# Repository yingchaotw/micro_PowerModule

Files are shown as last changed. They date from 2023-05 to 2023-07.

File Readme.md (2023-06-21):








# µPower Module

1. Purpose：

 - DC/DC Programmable small-wattage power supply
 - This project is [Open Source Hardware](https://www.oshwa.org/definition/chinese/)

2. Scope：
 - RFQ
     1. [x] Over voltage protection circuit
     2. [x] Support [MikroBus](https://www.mikroe.com/mikrobus) Foot Position
     3. [x] Positive and negative load voltage signals can be controlled by the H-bridge
     4. [x] Display voltage/current/wattage [Nokia 5110 LCD](https://github.com/EleonoreMizo/pedalevite/blob/master/doc/datasheets/Philips%20PCD8544%20-%20IC%2C%2048x84%20pixels%20matrix%20LCD%20controller%20(Nokia%205110).pdf), [TI-Nokia 5110 LCD](https://www.ti.com/lit/ml/swrp182/swrp182.pdf), [Nokia5110 LCD ](https://components101.com/displays/nokia-5110-lcd)
     5. [ ] MCU auto-regulator function
     6. [ ] Real time display of voltage and current
     7. [ ] Use a led to display local or remote mode
        1. [x] Standard Commands for Programmable Instruments

# HW Block Diagram


<BR/>
plug-in module. ex. Temperature sensor, etc.. <br/>

[Schematic Readme](./Circuit_microPowerModule/Readme.md)

# SW FlowChart
```mermaid
flowchart TD
subgraph "System Initialization"
  a("Check Communication<BR>(UART/I2C/SPI/..)") --> b(Check ADC) --> c(Read Sensor) --> d[buzzer <br> Make a sound]
end

subgraph "main"
    A(Start) --> B[System<br>Initialization]
    B --> C[Select Mode]
    C -->D["Remote <PC>"]
    C -->E["Local <encoder>"]
end

```

# Candidate Components

The required hardware units are divided into the following 6 items.
1. Power
2. Microcontroller
3. Interface
4. Sensor (Current/temperature)
5. Connector
6. Debug port

# PIN Assessment

[Raspberry Pi RP2040 GPIO Function](https://datasheets.raspberrypi.com/rp2040/rp2040-datasheet.pdf#_gpio_functions)

```
GPIO00 UART0 (Tx) --> RS485 (In)
GPIO01 UART0 (Rx) <-- RS485 (Out)
GPIO02 I2C1 (SDA) <-> (*Option) MikroBus SDA
GPIO03 I2C1 (SCL) --> (*Option) MikroBus SCL
GPIO04 I2C0 (SDA) <-> Power Management
GPIO05 I2C0 (SCL) --> Power Management
GPIO06 DS (MOSI)  --> Display Serial Input
GPIO07 DS (CLK)   --> Display Clock Input
GPIO08 UART1 (Tx) --> (*Option) MikroBus Tx
GPIO09 UART1 (Rx) <-- (*Option) MikroBus Rx
GPIO10 SPI1 (SCK) --> (*Option) MikroBus SCK
GPIO11 SPI1 (Tx)  --> (*Option) MikroBus SDI
GPIO12 SPI1 (Rx)  <-- (*Option) MikroBus SDO
GPIO13 SPI1 (nCS) --> (*Option) MikroBus CSS
GPIO14 DS (CE)    --> Display Chip Enable
GPIO15 DS (DC)    --> Display Data Command
GPIO16 PWM0_A     --> Buzzer
GPIO17 MkBus_RST  --> (*Option) MikroBus Reset
GPIO18 PWM1_A     --> (*Option) MikroBus PWM
GPIO19 PIO1_IRQ1  --> (*Option) MikroBus INT
GPIO20 PWM2_A     --> Encoder A phase
GPIO21 PWM2_B     --> Encoder B phase
GPIO22 RS_485 W/R --> RS485 (W/R)
GPIO23 DS_RST     --> Display Reset
GPIO24 ENC_SW     <-- Encoder Push Switch
GPIO25 PWM4 B     --> WS2512 LED Control
GPIO26 Monitor    <-- Input Power Monitor
GPIO27 ADC1       <-- (*Option) MikroBus ADC
GPIO28 Output_CTRL<-- Buck / Boost Switch
GPIO29 *Polarity  --> H-Bridge Control Load (Forward/Reverse)
```

# Potocol

[About Spec](./Document/Specification/Spec_link.md)
[Standard Commands for Programmable Instruments](https://www.ivifoundation.org/docs/scpi-99.pdf)

# Licenses & Disclaimer

<a rel="license" href="https://www.gnu.org/licenses/quick-guide-gplv3.en.html">GNU GPLv3</a> <br/> This work is licensed under a <a rel="license" href="https://www.gnu.org/licenses/quick-guide-gplv3.en.html"> GNU General Public License v3</a>.

If you have other ideas or suggestions, please feel free to submit an issue.
Welcome fork this repositories to provide contributions, or [buy me a coffee](https://ko-fi.com/yingchao_tw). thanks :)

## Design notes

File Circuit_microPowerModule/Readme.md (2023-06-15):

# Schematic







# ERC Report

```
ERC report (Thu 15 Jun 2023 20:53:31 CST, Encoding UTF8)

***** Sheet /

***** Sheet /main_contorl/

***** Sheet /Input_power/

***** Sheet /OutputPower/

***** Sheet /peripheral/

** ERC messages: 0  Errors 0  Warnings 0
```
[ERC File](./ERC.rpt)

# Incldue Library
[MikroBus](https://github.com/tclarke/kicad-mikroBUS)

# License & Disclaimer

<a rel="license" href="https://www.gnu.org/licenses/quick-guide-gplv3.en.html">GNU GPLv3</a> <br/> This work is licensed under a <a rel="license" href="https://www.gnu.org/licenses/quick-guide-gplv3.en.html"> GNU General Public License v3</a>.

If you have other ideas or suggestions, please feel free to submit an issue.
Welcome fork this repositories to provide contributions, or [buy me a coffee](https://ko-fi.com/yingchao_tw). thanks :)

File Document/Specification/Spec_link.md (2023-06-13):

# MCU

## Respberry Pi 2040
1. [official website](https://www.raspberrypi.com/documentation/microcontrollers/rp2040.html)
2. [DataSheet](https://datasheets.raspberrypi.com/rp2040/rp2040-datasheet.pdf)
3. [Getting Started](https://datasheets.raspberrypi.com/pico/getting-started-with-pico.pdf)
4. [Example C Code](https://github.com/raspberrypi/pico-examples/tree/master)
5. [Example Rust Code](https://github.com/rp-rs/rp2040-project-template)
6. [Waveshare Products](https://www.waveshare.com/product/rp2040-zero.htm)

# Load Driver
1. [L298-ST Website](https://www.st.com/en/motor-drivers/l298.html)
2. [L298N](https://www.st.com/resource/en/datasheet/l298.pdf)

# Protocol

[Standard Commands for Programmable Instrumentation](https://magna-power.com/assets/docs/html_ts/index-scpi.html)

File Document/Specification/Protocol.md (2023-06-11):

[Refer to SCPI website](https://magna-power.com/assets/docs/html_ts/index-scpi.html)

# SCPI

SYSTem:PRESet

SYSTem:VERSion

SYSTem:ERRor?

## CONFIGURE

CONFigure:TTLport

CONFigure:BEEPer

CONFigure:REMote

CONFigure:OUTPut

CONFigure:FOLDback

CONFigure:FOLDT

CONFigure:APGmode

CONFigure:MEASure:SPeed

CONFigure:AVG:TIMES

CONFigure:AVG:METHod

CONFigure:MSTSLV:NUMSLV

CONFigure:MSTSLV

## SOURCE

SOURce:VOLTage

SOURce:VOLTage:LIMit:{HIGH/LOW}

SOURce:VOLTage:PROTect:{HIGH/LOW}

SOURce:VOLTage:SLEW

SOURce:CURRent

SOURce:CURRent:LIMit:{HIGH/LOW}

SOURce:CURRent:PROTect:{HIGH/LOW}

SOURce:CURRent:SLEW

SOURce:CURRent:SLEWINF

SOURce:CURRent:SLEWINF DISABLE

SOUR:POW:PROT:HIGH

SOUR:DCON:{RISE/FALL}

## FETCJ

FETCh:VOLTage?

FETCh:CURRent?

FETCh:POWer?

FETCh:STATus?

## MEASURE

MEASure:VOLTage?

MEASure:CURRent?

MEASure:POWer?

## PROGRAM

PROGram:SELected

PROGram:LINK

PROGram:COUNT

PROGram:RUN

PROGram:PULL

PROGram:SAVE

PROGram:SEQuence:SELected

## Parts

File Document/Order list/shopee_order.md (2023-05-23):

# Module purchase list

|Item| Module name | Purchase Site | Price |
|:--:|---|---|---|
|1| MAX6675 | [Shopee](https://shp.ee/dakv5j8)| $98 |
|2| INA219[^INA219] | [Shopee](https://shp.ee/smzmpzs)| $98 |
|3| Buzzer | [Shopee](https://shp.ee/jidekbz)| $12 |
|4| Nokia 5110 | [Shopee](https://shp.ee/6gvhakf)| $99 |
|5| MAX485[^RS485] | [Shopee](https://shp.ee/49gyx4t) | $14 |
|6| Encoder | [Shopee](https://shp.ee/mrihj6k) | $19 |
|7| MCP4725 | [Shopee](https://shp.ee/vgvm73h) |$120|
|8| Boost | [Shopee](https://shp.ee/cv4cusn) |$15|
|9| Buck | [Shopee](https://shp.ee/qvjz9ka) |$32|
|10| OPA | [Shopee](https://shp.ee/ieca9kp) | $39|

[^INA219]:

[^RS485]:

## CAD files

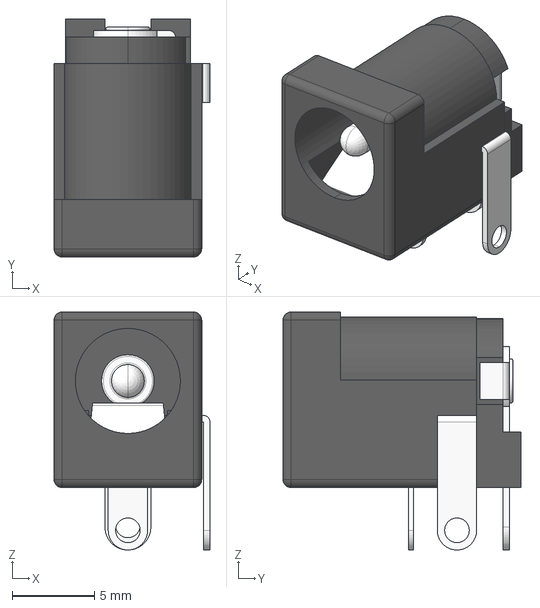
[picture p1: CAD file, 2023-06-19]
Circuit_microPowerModule/3D_Module/BarrelJack_Wuerth_6941xx301002.stp
9.50 x 14.5 x 14.5 mm

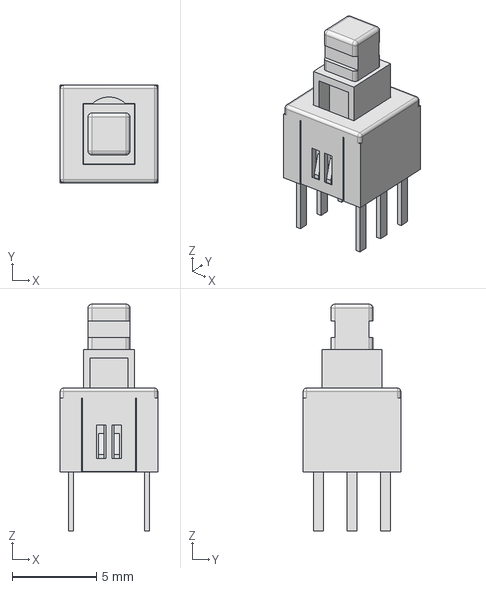
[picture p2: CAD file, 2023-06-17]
Circuit_microPowerModule/3D_Module/TL2203EE.stp
5.80 x 5.80 x 13.5 mm

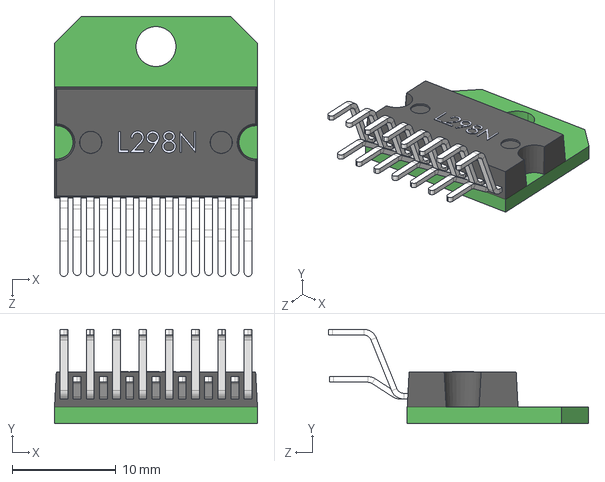
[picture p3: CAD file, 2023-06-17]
Circuit_microPowerModule/3D_Module/L298N.stp
19.6 x 9.09 x 25.1 mm

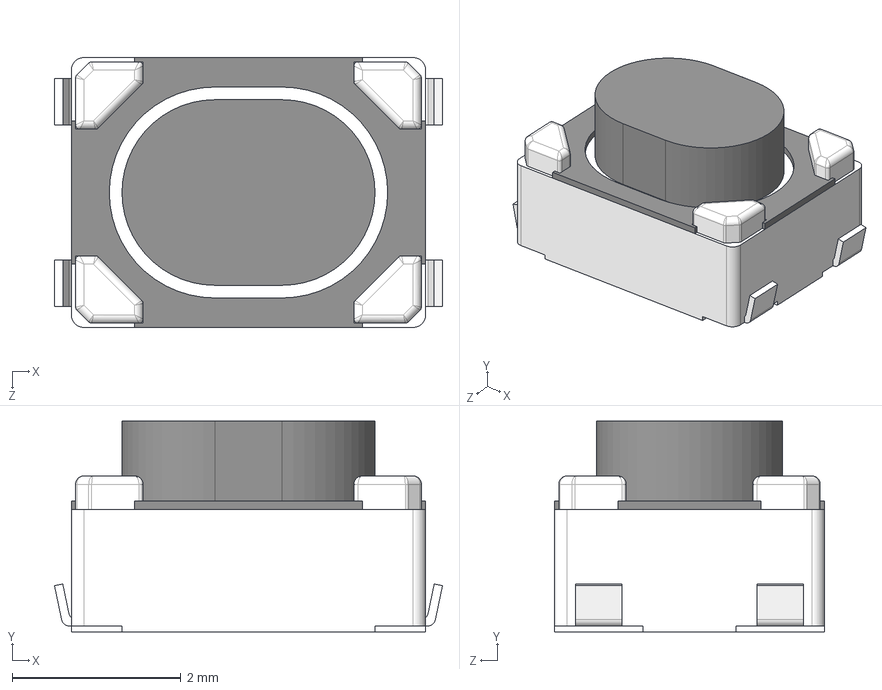
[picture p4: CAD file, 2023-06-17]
Circuit_microPowerModule/3D_Module/PTS815_SJK_250_SMTR_LFS.stp
4.60 x 2.50 x 3.20 mm

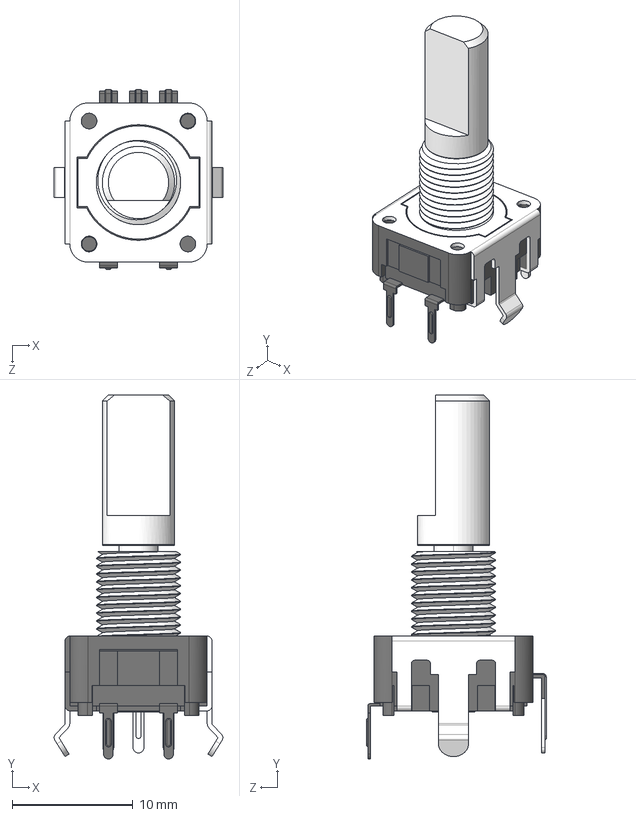
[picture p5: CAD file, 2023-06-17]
Circuit_microPowerModule/3D_Module/Encoder.stp
14.0 x 30.2 x 14.9 mm

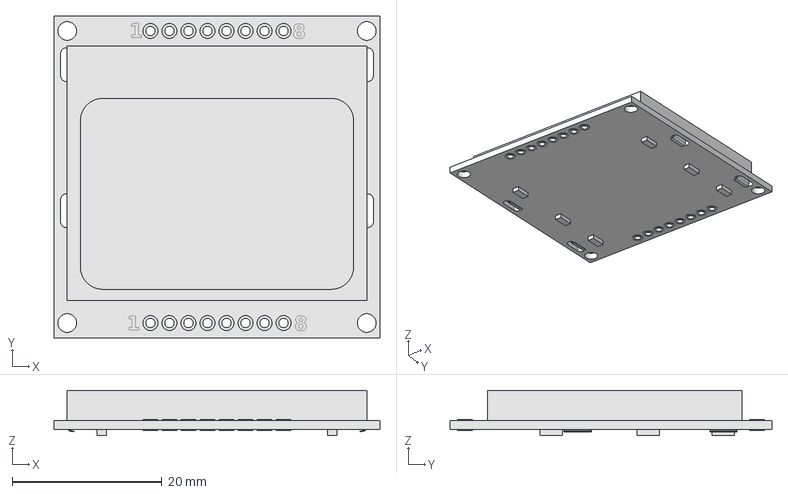
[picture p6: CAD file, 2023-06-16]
Circuit_microPowerModule/3D_Module/Nokia_5110_LCD.FCStd
43.5 x 43.0 x 6.05 mm

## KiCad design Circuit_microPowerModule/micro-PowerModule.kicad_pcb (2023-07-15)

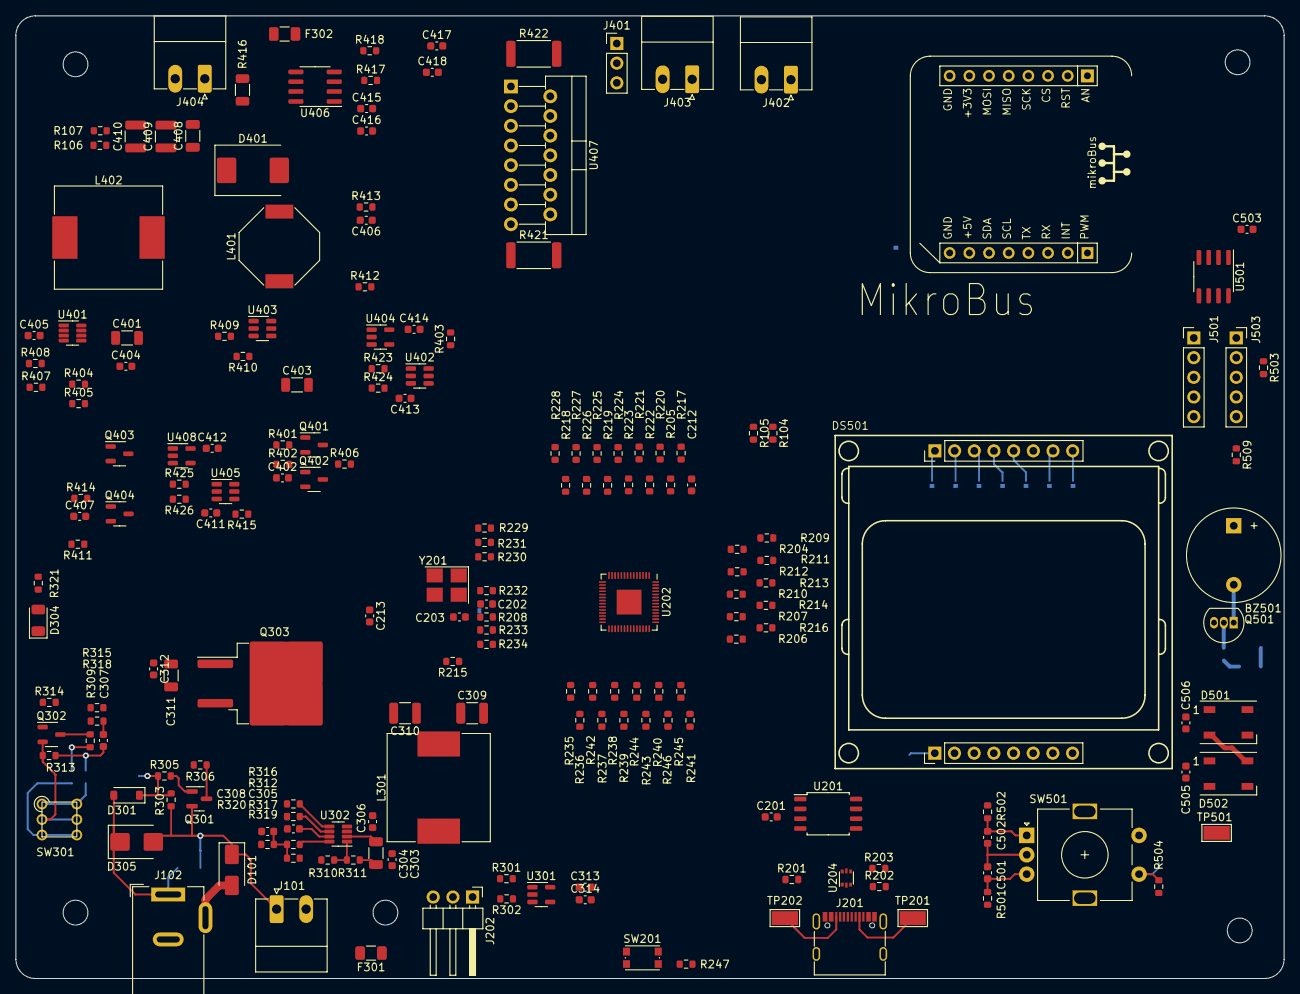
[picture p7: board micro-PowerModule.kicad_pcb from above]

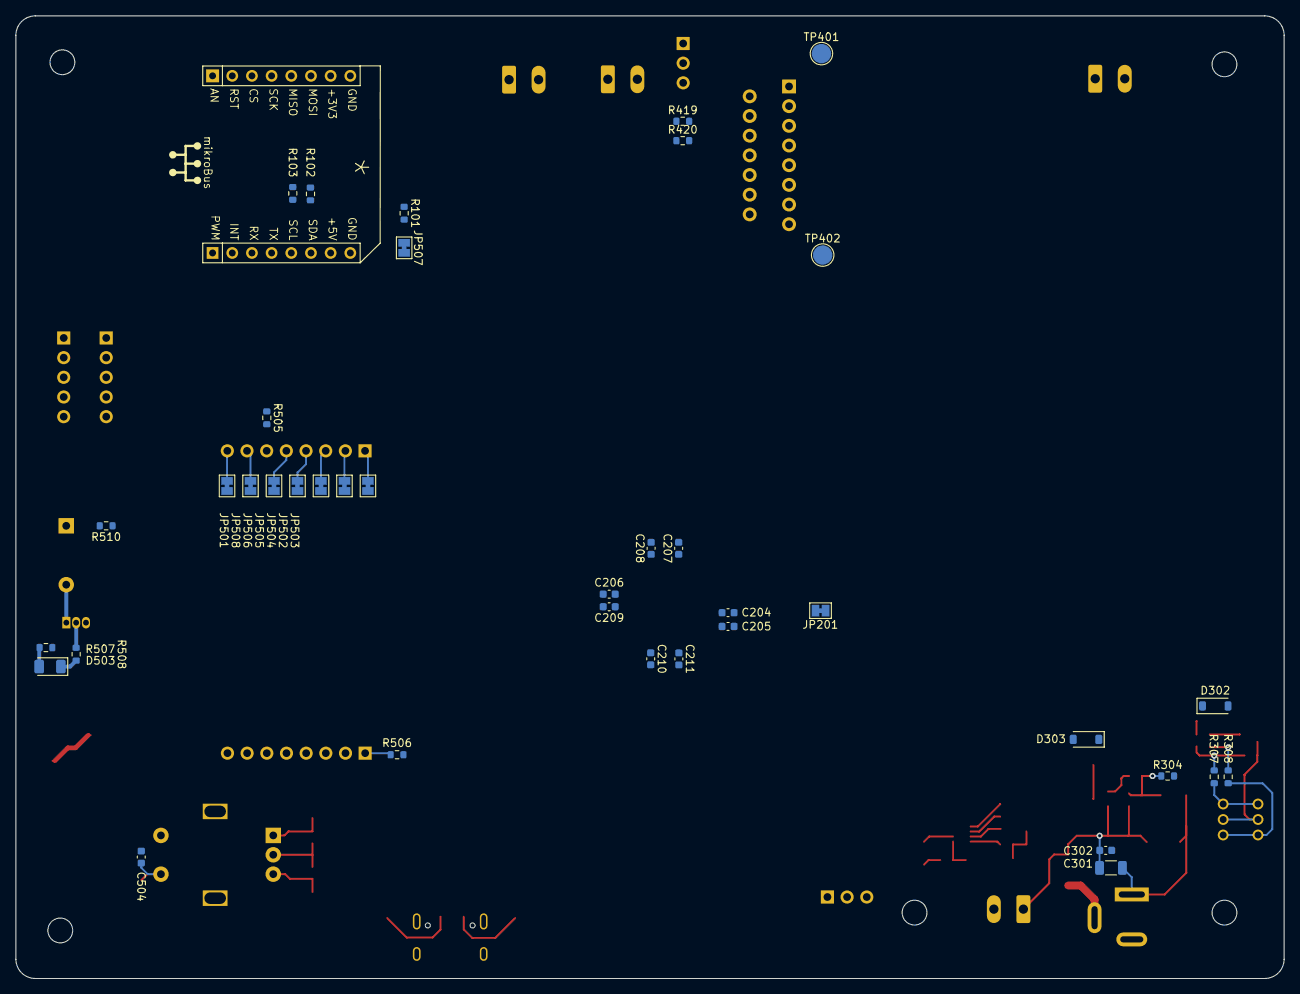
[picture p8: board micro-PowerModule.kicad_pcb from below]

Board: 2 copper layers, 163.7 x 124.2 mm, 235 parts (38 on the bottom side), 177 nets.

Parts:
BZ501: Buzzer; Buzzer_12x9.5RM7.6
C201, C204, C205, C206, C207, C208, C209, C210, C211, C212, C303, C305, C306, C313, C314, C404, C405, C411, C412, C413, C414, C415, C416, C417, C418, C501, C502, C503, C505, C506: 100nF/50V; C_0603_1608Metric
C202, C203: 15pF/50V; C_0603_1608Metric
C213, C402, C407: 10pF/50V; C_0603_1608Metric
C301, C311: 47u/50V; C_1206_3216Metric
C302, C312: 100n/50V; C_0603_1608Metric
C304, C401, C403, C408: 22uF/50V; C_1206_3216Metric
C307: 10n/50V; C_0603_1608Metric
C308, C406: 33pF/50V; C_0603_1608Metric
C309, C310, C409, C410: 22uF/50V; C_1210_3225Metric
C504: 10nF/50V; C_0603_1608Metric
D101: SS54; D_SMA
D301: Zener_24V/500mW; D_SOD-123
D302: DNP; D_SOD-123
D303: Zener_20V/500mW; D_SOD-123
D304: LED_Green; LED_1206_3216Metric
D305: TPSMB36CA; D_SMB
D401: SS34; D_SMC
D501, D502: WS2812B; LED_WS2812B_PLCC4_5.0x5.0mm_P3.2mm
D503: LED_Blue; LED_1206_3216Metric
DS501: NOKIA 5110; Nokia_5110_module
F301, F302: 60V/100mA; Fuse_1206_3216Metric
J101, J402, J403, J404: Screw_Terminal_01x02; PhoenixContact_MC_1,5_2-G-3.81_1x02_P3.81mm_Horizontal
J102: Jack-DC; BarrelJack_Wuerth_6941xx301002
J201: USB_C_Receptacle_USB2.0; USB_C_Receptacle_G-Switch_GT-USB-7010ASV
J202: Debug; PinHeader_1x03_P2.54mm_Horizontal
J401: Conn_01x03; PinHeader_1x03_P2.54mm_Vertical
J501: HDR-2.54 Male 1x5; PinHeader_1x05_P2.54mm_Vertical
J502: MikroBus; MIKROBUS_CONN
J503: HDR-2.54 Female 1x5; PinSocket_1x05_P2.54mm_Vertical
JP201, JP501, JP502, JP503, JP504, JP505, JP506, JP507, JP508: SolderJumper_2_Bridged; SolderJumper-2_P1.3mm_Bridged_Pad1.0x1.5mm
L301, L402: 4.7uH; L_Sunlord_MWSA1204S-4R7
L401: 33uH; L_Bourns-SRU1028_10.0x10.0mm
Q301: MMBT3906; SOT-23
Q302, Q402, Q404: RK7002BM; SOT-23-3
Q303: IRF5305S; TO-263-2
Q401, Q403: RU1C002ZP; SOT-23-3
Q501: S8550; TO-92_Inline
R101, R201, R216, R309, R318, R401, R411, R417, R418, R423, R425, R506, R509, R510: 0R/5%; R_0603_1608Metric
R102, R103, R106, R107, R204, R205, R303, R304, R305, R306, R307, R501, R502, R504: 10K/5%; R_0603_1608Metric
R104, R105: 22R/5%; R_0603_1608Metric
R202, R203: 5.1K/5%; R_0603_1608Metric
R206, R207: 27R/5%; R_0603_1608Metric
R208, R314, R321, R403, R415, R419, R420, R424, R426, R507, R508: 1K/5%; R_0603_1608Metric
R209, R210, R211, R212, R213, R214, R217, R218, R219, R220, R221, R222, R223, R224, R225, R226, R227, R228, R229, R230, R231, R232, R233, R234, R235, R236, R237, R238, R239, R240, R241, R242, R243, R244, R245, R246, R316, R407: 10R/5%; R_0603_1608Metric
R215, R247: 1K/DNP; R_0603_1608Metric
R301, R402, R414: 22K/5%; R_0603_1608Metric
R302: 3.3K/5%; R_0603_1608Metric
R308: 100R/5%; R_0603_1608Metric
R310, R313, R315, R404, R408: 100K/5%; R_0603_1608Metric
R311: 7.5K/5%; R_0603_1608Metric
R312: 499K/5%; R_0603_1608Metric
R317: 33K/5%; R_0603_1608Metric
R319: 12.7K/5%; R_0603_1608Metric
R320: 40.2K/5%; R_0603_1608Metric
R405: 9K1/5%; R_0603_1608Metric
R406: 47R/5%; R_0603_1608Metric
R409, R410: 2.2K/5%; R_0603_1608Metric
R412: 62K/5%; R_0603_1608Metric
R413: 20.5K/5%; R_0603_1608Metric
R416: 0.1R/1%; R_1206_3216Metric
R421, R422: 0.5R/5%; R_2512_6332Metric
R503: 120R/5%; R_0603_1608Metric
R505: DNP; R_0603_1608Metric
REF1, REF1#2, REF1#3, REF1#4, REF1#5: MountingHole_3.2mm_M3_ISO7380
SW201: KMR2; SW_Push_1P1T_NO_CK_KMR2
SW301: SW_DPDT_x2; SW_DIP_5176_SPDT
SW501: RotaryEncoder_Switch; RotaryEncoder_Alps_EC11E-Switch_Vertical_H20mm
TP201, TP202, TP501: TestPoint_Small; TestPoint_Keystone_5015_Micro-Minature
TP401, TP402: TestPoint; TestPoint_Pad_D2.5mm
U201: W25Q128JVS; SOIC-8_5.23x5.23mm_P1.27mm
U202: RP2040; QFN-56-1EP_7x7mm_P0.4mm_EP3.2x3.2mm
U204: USBLC6-2P6; SOT-666
U301, U404, U408: OPA376xxDBV; SOT-23-5
U302, U401: MP2315S; TSOT-23-8
U402, U405: MCP4725xxx-xCH; SOT-23-6
U403: MT3608; SOT-23-6
U406: INA219BxD; SOIC-8_3.9x4.9mm_P1.27mm
U407: L298N; TO-220-15_P2.54x2.54mm_StaggerOdd_Lead4.58mm_Vertical
U501: MAX485E; SOIC-8_3.9x4.9mm_P1.27mm
Y201: 12MHz; Crystal_SMD_SeikoEpson_FA238V-4Pin_3.2x2.5mm_HandSoldering

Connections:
+1V2: C204.1, C205.1, C206.1, R216.1, U202.23 (DVDD), U202.50 (DVDD)
+3V3: C201.1, C207.1, C208.1, C209.1, C210.1, C211.1, C212.1, C308.2, C309.1, C310.1, C313.1, C314.1, C411.1, C412.1, C413.1, C414.1, C415.1, C416.1, C503.1, C505.1, C506.1, D501.1 (VDD), D502.1 (VDD), J502.7, JP508.2 (B), L301.2, Q401.1 (D), Q403.1 (D), R102.1, R103.1, R106.1, R107.1, R204.2, R205.2, R247.1, R320.1, R402.2, R414.2, R415.2, R419.1, R501.1, R502.1, R504.1, R506.1, R507.1, R510.1, U201.8 (VCC), U202.1 (IOVDD), U202.10 (IOVDD), U202.22 (IOVDD), U202.33 (IOVDD), U202.42 (IOVDD), U202.43 (ADC_AVDD), U202.44 (VREG_IN), U202.48 (USB_VDD), U202.49 (IOVDD), U301.5 (V+), U402.3 (VDD), U404.5 (V+), U405.3 (VDD), U406.5 (VS), U408.5 (V+), U501.8 (VCC)
+5V: C417.1, C418.1, J502.10, R509.2, U407.4 (Vs)
+VDC: C303.1, C304.1, C311.1, C312.1, C401.1, C403.1, L401.1, Q303.1 (D), R312.2, R321.1, U302.2 (IN), U401.2 (IN), U403.5 (IN)
/BUCK/~BOOST: R104.2, R245.2
/Buzzer_PWM: D503.1 (K), R233.2, R508.1
/Forward/~Reverse: R105.2, R246.2
/Mk_ADC: J502.1, R244.2
/Mk_CS: J502.3, R230.2
/Mk_INT: J502.15, R236.2
/Mk_PWM: J502.16, R235.2
/Mk_RST: J502.2, R234.2
/Mk_Rx: J502.14, R226.2
/Mk_SCL: J502.12, R103.2, R220.2
/Mk_SDA: J502.11, R102.2, R219.2
/Mk_SDI: J502.6, R228.2
/Mk_SDK: J502.4, R227.2
/Mk_SDO: J502.5, R229.2
/Mk_Tx: J502.13, R225.2
/OutputPower/Boost_FB: R410.2, U408.1, U408.4 (-)
/OutputPower/BuckBoostOutput: C408.1, C409.1, C410.1, D401.1 (K), L402.2, R409.1, R416.1, U406.8 (IN+)
/OutputPower/Buck_EN/Boost_~EN: R104.1, R401.1
/OutputPower/Buck_FB: R412.2, U404.1, U404.4 (-)
/OutputPower/EN_MP2315S: C402.1, Q401.2 (G), Q402.2 (G), R401.2, R402.1, U401.6 (EN)
/OutputPower/EN_MT3608: R406.2, U403.4 (EN)
/OutputPower/H_Bridge_Out1: J402.1, U407.2 (OUT1)
/OutputPower/H_Bridge_Out2: J402.2, U407.3 (OUT2)
/OutputPower/H_Bridge_Out3: J403.1, U407.13 (OUT3)
/OutputPower/H_Bridge_Out4: J403.2, U407.14 (OUT4)
/OutputPower/Load_Forward: C407.1, Q403.2 (G), Q404.2 (G), R411.2, R414.1, U407.5 (IN1), U407.10 (IN3)
/OutputPower/Load_Reverse: Q403.3 (S), Q404.1 (D), U407.7 (IN2), U407.12 (IN4)
/OutputPower/Load_direction: R105.1, R411.1
/OutputPower/PWR_OUT: C406.2, J404.1, R413.1, R416.2, U406.7 (IN-), U407.9 (Vss)
/PM_SCL: R106.2, R221.2, U402.5 (SCL), U405.5 (SCL), U406.4 (SCL)
/PM_SDA: R107.2, R222.2, U402.4 (SDA), U405.4 (SDA), U406.3 (SDA)
/PWR_IN: C301.1, C302.1, C307.1, D101.1 (K), D303.1 (K), D305.2 (A2), J101.1, Q301.2 (E), Q303.3 (S), R301.1, R303.1, R307.1, R313.1, R315.1
/PWR_Monitor: R243.2, U301.1, U301.4 (-)
/RP_DS_CHIPENABLE: JP502.1 (A), R231.2
/RP_DS_CLK: JP506.1 (A), R224.2
/RP_DS_DATACMD: JP504.1 (A), R232.2
/RP_DS_MOSI: JP505.1 (A), R223.2
/RP_DS_RESET: JP503.1 (A), R240.2
/RP_ENC_A: C502.1, R237.2, R502.2, SW501.A
/RP_ENC_B: C501.1, R238.2, R501.2, SW501.B
/RP_ENC_SW: C504.1, R241.2, R504.2, SW501.S1
/UARTrx_RS485in: R217.2, U501.4 (DI)
/UARTtx_RS485out: R218.2, U501.1 (RO)
/main_contorl/LET_CTRL: D501.4 (DIN), R242.2
/main_contorl/QSPI_NSS: R204.1, R209.2, U201.1 (~CS)
/main_contorl/QSPI_SCLK: R214.2, U201.6 (CLK)
/main_contorl/QSPI_SD0: R210.2, U201.5 (DI(IO0))
/main_contorl/QSPI_SD1: R211.2, U201.2 (DO(IO1))
/main_contorl/QSPI_SD2: R212.2, U201.3 (IO2)
/main_contorl/QSPI_SD3: R213.2, U201.7 (IO3)
/main_contorl/RS485_W/~R: R239.2, U501.2 (~RE), U501.3 (DE)
/main_contorl/SWCLK: J202.1, U202.24 (SWCLK)
/main_contorl/SWDIO: J202.3, U202.25 (SWD)
/main_contorl/USB+: R206.2, U204.4 (I/O2)
/main_contorl/USB-: R207.2, U204.6 (I/O1)
/main_contorl/USB_N: J201.A7 (D-), J201.B7 (D-), U204.1 (I/O1)
/main_contorl/USB_P: J201.A6 (D+), J201.B6 (D+), U204.3 (I/O2)
/main_contorl/~RESET: C213.1, R205.1, R247.2, SW201.2, U202.26 (RUN)
/main_contorl/~USB_N: R207.1, U202.46 (USB_DM)
/main_contorl/~USB_P: R206.1, U202.47 (USB_DP)
/peripheral/485A: J501.3, J503.3, R503.2, U501.6 (A)
/peripheral/485B: J501.2, J503.2, R503.1, U501.7 (B)
/peripheral/DS_Backlight: DS501.7b (BL), DS501.8a (BL), JP508.1 (A)
/peripheral/DS_ChipEnable: DS501.2b (CE), DS501.3a (SEC), JP502.2 (B)
/peripheral/DS_Clock: DS501.5b (CLK), DS501.7a (SCLK), JP506.2 (B)
/peripheral/DS_Data/Command: DS501.3b (DC), DS501.5a (D/C), JP504.2 (B)
/peripheral/DS_Serial_Data: DS501.4b (DIN), DS501.6a (DN/MOSI), JP505.2 (B)
/peripheral/DS_~Reset: DS501.1b (RST), DS501.4a (RST), JP503.2 (B)
/peripheral/M_GND: J502.8, J502.9, JP507.2 (B)
/peripheral/Mikro_GND: JP507.1 (A), R101.2
GNDPWR: C301.2, C302.2, C303.2, C304.2, C305.2, C309.2, C310.2, C311.2, C312.2, C401.2, C403.2, C404.2, C408.2, C409.2, C410.2, D301.2 (A), D304.1 (K), D305.1 (A1), F301.2, F302.1, J101.2, J102.1, J102.2, J404.2, R304.2, R306.2, R308.2, R309.2, R311.1, R319.2, R405.1, R421.2, R422.2, U302.4 (GND), U401.4 (GND), U403.2 (GND), U407.8 (GND)
GNDREF: C201.2, C204.2, C205.2, C206.2, C207.2, C208.2, C209.2, C210.2, C211.2, C212.2, C213.2, C313.2, C314.2, C402.2, C407.2, C411.2, C412.2, C413.2, C414.2, C415.2, C416.2, C417.2, C418.2, C501.2, C502.2, C503.2, C504.2, C505.2, C506.2, D501.3 (VSS), D502.3 (VSS), DS501.2a (GND), DS501.8b (GND), F301.1, F302.2, J201.A1 (GND), J201.A12 (GND), J201.B1 (GND), J201.B12 (GND), J202.2, JP201.1 (A), JP501.1 (A), Q402.3 (S), Q404.3 (S), Q501.3 (C), R101.1, R201.2, R202.2, R203.1, R302.2, R403.2, R417.2, R418.2, R420.2, R424.1, R426.1, SW201.1, SW501.C, SW501.S2, U201.4 (GND), U202.57 (GND), U204.2 (GND), U301.2 (V-), U402.2 (VSS), U404.2 (V-), U405.2 (VSS), U406.6 (GND), U408.2 (V-), U501.5 (GND), Y201.2, Y201.4
unnamed: BZ501.2 (+), Q501.1 (E)
unnamed: BZ501.1 (-), R510.2
unnamed: C202.1, Y201.1
unnamed: C203.1, Y201.3
unnamed: C203.2, R208.2
unnamed: C306.1, R316.2
unnamed: C308.1, R317.1, R319.1, R320.2
unnamed: C405.1, R407.2
unnamed: C406.1, R408.1, R412.1, R413.2
unnamed: D101.2 (A), J102.3
unnamed: D301.1 (K), R303.2, R304.1, R305.1
unnamed: D302.2 (A), R314.2, R315.2, R318.1
unnamed: C307.2, D302.1 (K), D303.2 (A), Q303.2 (G), R318.2
unnamed: D304.2 (A), R321.2
unnamed: D401.2 (A), L401.2, U403.1 (SW)
unnamed: D501.2 (DOUT), D502.4 (DIN)
unnamed: D502.2 (DOUT), TP501.1
unnamed: D503.2 (A), R507.2
unnamed: DS501.1a (VCC), DS501.6b (VCC), R505.2, R506.2
unnamed: J201.A5 (CC1), R202.1
unnamed: J201.B5 (CC2), R203.2
unnamed: J201.A8 (SBU1), TP201.1
unnamed: J201.B8 (SBU2), TP202.1
unnamed: J201.S1 (SHIELD), R201.1
unnamed: J401.1, R419.2
unnamed: J401.2, U407.6 (EnA), U407.11 (EnB)
unnamed: J401.3, R420.1
unnamed: J501.1, J503.1, JP501.2 (B)
unnamed: JP201.2 (B), U202.19 (TESTEN)
unnamed: Q301.1 (B), R305.2
unnamed: Q301.3 (C), R306.1
unnamed: Q302.1 (D), R314.1
unnamed: Q302.2 (G), R313.2, SW301.2 (B), SW301.5 (B)
unnamed: Q302.3 (S), R309.1
unnamed: Q401.3 (S), Q402.1 (D), R406.1
unnamed: Q501.2 (B), R508.2
unnamed: R307.2, SW301.1 (A), SW301.4 (A)
unnamed: R308.1, SW301.3 (C), SW301.6 (C)
unnamed: R217.1, U202.2 (GPIO0)
unnamed: R218.1, U202.3 (GPIO1)
unnamed: R219.1, U202.4 (GPIO2)
unnamed: R220.1, U202.5 (GPIO3)
unnamed: R221.1, U202.6 (GPIO4)
unnamed: R222.1, U202.7 (GPIO5)
unnamed: R223.1, U202.8 (GPIO6)
unnamed: R224.1, U202.9 (GPIO7)
unnamed: R225.1, U202.11 (GPIO8)
unnamed: R226.1, U202.12 (GPIO9)
unnamed: R227.1, U202.13 (GPIO10)
unnamed: R228.1, U202.14 (GPIO11)
unnamed: R229.1, U202.15 (GPIO12)
unnamed: R230.1, U202.16 (GPIO13)
unnamed: R231.1, U202.17 (GPIO14)
unnamed: R232.1, U202.18 (GPIO15)
unnamed: R233.1, U202.27 (GPIO16)
unnamed: R234.1, U202.28 (GPIO17)
unnamed: R235.1, U202.29 (GPIO18)
unnamed: R236.1, U202.30 (GPIO19)
unnamed: R237.1, U202.31 (GPIO20)
unnamed: R238.1, U202.32 (GPIO21)
unnamed: R239.1, U202.34 (GPIO22)
unnamed: R240.1, U202.35 (GPIO23)
unnamed: R241.1, U202.36 (GPIO24)
unnamed: R242.1, U202.37 (GPIO25)
unnamed: R243.1, U202.38 (GPIO26_ADC0)
unnamed: R244.1, U202.39 (GPIO27_ADC1)
unnamed: R245.1, U202.40 (GPIO28_ADC2)
unnamed: R246.1, U202.41 (GPIO29_ADC3)
unnamed: R214.1, U202.52 (QSPI_SCLK)
unnamed: R210.1, U202.53 (QSPI_SD0)
unnamed: R211.1, U202.55 (QSPI_SD1)
unnamed: R212.1, U202.54 (QSPI_SD2)
unnamed: R213.1, U202.51 (QSPI_SD3)
unnamed: R209.1, U202.56 (QSPI_SS)
unnamed: R216.2, U202.45 (VREG_VOUT)
unnamed: C202.2, R215.1, U202.20 (XIN)
unnamed: R208.1, R215.2, U202.21 (XOUT)
unnamed: R301.2, R302.1, U301.3 (+)
unnamed: R310.1, R311.2, U302.1 (AAM)
unnamed: R316.1, U302.5 (BST)
unnamed: R312.1, U302.6 (EN)
unnamed: R317.2, U302.8 (FB)
unnamed: C306.2, L301.1, U302.3 (SW)
unnamed: C305.1, R310.2, U302.7 (VCC)
unnamed: R404.1, R405.2, U401.1 (AAM)
unnamed: R407.1, U401.5 (BST)
unnamed: R408.2, U401.8 (FB)
unnamed: C405.2, L402.1, U401.3 (SW)
unnamed: C404.1, R404.2, U401.7 (VCC)
unnamed: R403.1, U402.6 (A0)
unnamed: R423.2, U402.1 (VOUT)
unnamed: R409.2, R410.1, U403.3 (FB)
unnamed: R423.1, R424.2, U404.3 (+)
unnamed: R415.1, U405.6 (A0)
unnamed: R425.2, U405.1 (VOUT)
unnamed: R418.1, U406.2 (A0)
unnamed: R417.1, U406.1 (A1)
unnamed: R422.1, TP401.1, U407.1 (SENSE_A)
unnamed: R421.1, TP402.1, U407.15 (SENSE_B)
unnamed: R425.1, R426.2, U408.3 (+)
VBUS: J201.A4 (VBUS), J201.A9 (VBUS), J201.B4 (VBUS), J201.B9 (VBUS), J501.5, J503.5, R505.1, R509.1, U204.5 (VBUS)

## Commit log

2023-05-19 update HW block diagram
    added kicad schematic, sw flowchart
    [micro-PowerModule.kicad_pcb, micro-PowerModule.kicad_sch]
2023-05-20 decision MCU-RP2040
    added RP2040 to circuit
    [micro-PowerModule.kicad_sch, microcontroller_unit.kicad_sch]
2023-05-22 added MP2315S lib, updated circuit
    updated block diagram by-sa
    [OutputPower.kicad_sch, micro-PowerModule.kicad_sch, microcontroller_unit.kicad_sch]
2023-05-23 new RFQ, update circuit
    [micro-PowerModule.kicad_sch, microcontroller_unit.kicad_sch]
2023-05-24 added input power OVP circuit
    update buck-boost circuit
    [OutputPower.kicad_sch, input_power.kicad_sch, microcontroller_unit.kicad_sch]
2023-05-25 added boost circuit
    create peripheral schematic
    [OutputPower.kicad_sch, input_power.kicad_sch, microcontroller_unit.kicad_sch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]
2023-05-26 added mikrobus header
    added filter capacitance, I2C pull-up resistor
    [OutputPower.kicad_sch, micro-PowerModule.kicad_sch, microcontroller_unit.kicad_sch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]
2023-05-27 added Nokia 5110 LCD symbol
    linked some component pin
    [micro-PowerModule.kicad_sch, microcontroller_unit.kicad_sch, peripheral.kicad_sch]
2023-05-28 added schematic svg file
    added encoder wire, mikrobus connect
    [OutputPower.kicad_sch, input_power.kicad_sch, micro-PowerModule.kicad_sch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]
2023-05-30 define mcu pinout to mikrobus
    update hw block diagram file type
    [micro-PowerModule.kicad_sch, microcontroller_unit.kicad_sch, peripheral.kicad_sch]
2023-05-31 Completed microcontroller unit pin planning
    update schematic
    [OutputPower.kicad_sch, input_power.kicad_sch, micro-PowerModule.kicad_sch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]
2023-06-05 change licenses
    updated some footprint, create nokia 5110 lcd module pcb symbol, updated reademe
    [OutputPower.kicad_sch, input_power.kicad_sch, micro-PowerModule.kicad_sch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]
2023-06-06 update components footprint
    check boost VR component, added Nokia 5110 LCD 3D module
    [Nokia_5110_LCD.FCStd, OutputPower.kicad_sch, input_power.kicad_sch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]
2023-06-10 update schematic
    added pin assessment to readme
    [OutputPower.kicad_sch, input_power.kicad_sch, micro-PowerModule.kicad_sch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]
2023-06-11 added protocol document
    update pin assessment
    [OutputPower.kicad_sch]
2023-06-13 added H-Bridge
    Control load forward or reverse (current direction)
    [OutputPower.kicad_sch, input_power.kicad_sch, micro-PowerModule.kicad_sch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]
2023-06-14 modify ERC error, protect components
    [OutputPower.kicad_sch, input_power.kicad_sch, micro-PowerModule.kicad_sch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]
2023-06-15 modify ERC warning
    modify OPA, TVS-Diode, Cap
    [OutputPower.kicad_sch, input_power.kicad_sch, micro-PowerModule.kicad_sch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]
2023-06-16 start pcb layout
    [Nokia_5110_LCD.FCStd, micro-PowerModule.kicad_pcb, micro-PowerModule.kicad_sch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]
2023-06-17 update pcb layout component
    target to smaller pcb size
    [BarrelJack_Wuerth_6941xx301002.stp, Encoder.stp, L298N.stp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]
2023-06-19 set board edge cut
    [BarrelJack_Wuerth_6941xx301002.stp, micro-PowerModule.kicad_pcb, peripheral.kicad_sch]
2023-06-21 Finishing MCU Peripheral Passive Components
    [micro-PowerModule.kicad_pcb, microcontroller_unit.kicad_sch]
2023-06-22 update system power circuit layout
    [OutputPower.kicad_sch, input_power.kicad_sch, micro-PowerModule.kicad_pcb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]
2023-06-27 update output inductor footprint
    [OutputPower.kicad_sch, micro-PowerModule.kicad_pcb]
2023-06-29 modify DAC to Voltage follwers
    [OutputPower.kicad_sch, micro-PowerModule.kicad_pcb]
2023-07-05 update pcb component layout
    [micro-PowerModule.kicad_pcb]
2023-07-13 update pcb trace layout
    [micro-PowerModule.kicad_pcb]
2023-07-15 update U302 PCB Layout
    [micro-PowerModule.kicad_pcb]

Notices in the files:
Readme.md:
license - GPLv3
